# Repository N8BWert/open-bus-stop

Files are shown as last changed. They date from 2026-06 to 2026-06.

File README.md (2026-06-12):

# Informal Bus Display

## Motivation

While traveling abroad, I noticed that a lot of cities (specifically in the Netherlands) have displays at bus stops detailing the next bus arrival.  This is relatively unheard of in the United States (except for at certain Bus Rapid Transit stations) so I figured it would be interesting to create an informal bus display.  This informal bus display is a simple LCD screen attached to a low-powered microcontroller, but we can use the RTC to try to display the next bus arrivals.

## Description

To make the bus riding experience more enjoyable and reliable, a small low-powered microcontroller display can be created to display the static arrival times of buses.  These displays can be created inexpensively and placed throughout the city informally by residents to aid bus riders in knowing when their next bus is scheduled.

To further extend this concept, our team is also looking to create a set of "towers" (raspberry pis) that can relay real-time bus arrival schedules to the low-powered displays via LoRA radios as well as creating a mapping software to display the location of the various bus-stop displays and "towers" to visualize the adoption of the informal bus stop displays.

## Technical Details

A small low-power microcontroller can be attached at each bus stop around the city.  The microcontroller will have the static table of the bus arrival times for the given bus stop.  Additionally, to improve the accuracy of the microcontroller displays a second “tower” can be created from a raspberry pi and a LoRA-capable radio.  The raspberry pi can ping the relevant transit agency’s API to determine the real-time bus arrival times for all bus stations in its local range.  Then it can relay this information via a LoRA radio to the low-power microcontroller displays to give them real-time bus arrival data.  To contribute to the formation of an informal network of the bus displays and towers a web app can be created.  The towers will relay their GPS coordinate as well as the bus stops they are serving to the web application which can create an autonomic map of the serviced area of the informal bus displays.  Additionally, the low-power microcontrollers will still be able to display static bus arrival times when not connected via LoRA, but will need to be manually registered with the central website to be displayed.

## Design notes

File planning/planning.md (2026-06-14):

# Planning

For full production we will need these displays to effectively work without needing to be modified at all.  This means minimizing power consumption and cost, while also enabling the device to recover from full power loss.  With the current prototype, the rp2040's RTC will not recover from a full power loss meaning we'll need a replacement.  Additionally, the lcd1602 display does not have great visibility and the backlight is very costly.  Finally, We will need to use a solar panel to recharge the lipo battery powering the microcontrollers.

## ESP32-C3 Power Stats using Embassy

Active (CPU running without Wifi): ~20-30mA
Light Sleep (Embassy async wait) - ~130uA

Program Loop:
1. Check the RTC time
2. Update the display
3. Light Sleep for 30 seconds

Assuming steps one and two take 500 milliseconds, this gives us the following power draw:
Steps 1 and 2: 30mA * 500 milliseconds
Step 3: 130uA * 30 seconds

So one loop is 30.13mA at 30.5 seconds meaning we are consuming 30.13mA * 30.5s = 918.965mAs = 0.255mAh

Assuming the device was working 24 hours a day, this would be a total of 6.126mAh per day

## 6v 200mA Solar Panel Recharge

Expecting 75% efficiency and full sunlight for 4 hours a day we can recharge about 200mA * 0.75% * 4 hours = 600mA, which we will consider our absolute budget.

## LCD1602 Power Stats

For the prototype I used the LCD1602 to display the upcoming bus arrivals.  With the blue backlight it has a power draw of roughly 45-55mA.

This means over a day of it being on for 24 hours we would consume 1080mAh-1320mAh.

This far exceeds the 600mA budget of our system so we will not be able to use it.

## SSD1309 OLED Display

The display I used in my prototype consumes way too much power to work for the final product.  Another display I'm considering using is a 2.4" SSD1309 display.  This is relatively the same size as the LCD1602 display, but should have a significantly lower power draw.

The SSD1309 seems to draw roughly 20mA for my current application which would mean over 24 hours we would consume 480mAh.

This is solidly within our solar panel recharge rate (6.126 + 480) < 600mA so this is the way to go.

The main downside of the SSD1309 is it is a bit more expensive than the LCD1602, but I think that being able to actually make it through a day is more important than the price in this case.  Additionally, the LCD1602 is hard to see at different angles (and in the sun), whereas the SSD1309 OLED display is visible at all angles and in most levels of sunlight.

## SSD1306 OLED Display

The SSD1309 would be perfect for this project, but its relatively expensive for some reason.  I swear in the past I found them for ~$4-5 a piece, but they're like $12 on the low end now.  For that reason, I'm going to make a prototype with the SSD1306 I2C displays.  They're about 1x1" in display size, but they're also ~$3 a piece.  I'm not 100% certain that they're large enough to be read from near the bus stop though so I need to test that before I commit.

## RTC Selection

The DS3231 seems like the goto Real Time Clock Module for most applications I've seen on the internet so I'll probably choose that for perpetuity

## High-Level Circuit Diagram

```
Solar Cell ---> BQ24074 Solar Cell Lipo Charger ---> LiPo Battery ---> ESP32-C3 ---> SSD1309 Display
                                                                          |
                                                                          |
                                                                          |
                                                                          ---------> RTC (coin cell battery)
                                                                          |
                                                                          |
                                                                          |
                                                                          ---------> Power Switch (power on and off)
```

## Other Considerations

This device needs to be waterproof considering it will be sitting in the elements for years.  In Atlanta, the materials matter a lot considering it can get very hot and humid.  However, I need this to be able to be created by the general population so I think it will need to be able to be 3d printed and/or laser cuttable.  For this reason I will 3d print the majority of the body with white PETG (white to prevent overheating, plus there is UV resistant PETG) and create a front face out of laser cut acrylic.  These are easily accessible hobby manufacturing materials meaning that anyone will be able to make the displays.  To access the PCB for firmware updates and repairs we'll use an O-ring to mate two parts of the 3d printed enclosure.

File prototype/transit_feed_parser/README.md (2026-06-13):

# Transit Feed Parser

## Description

For a large number of transit agencies (at least in the US), google creates a General Transit Feed Specification in partnership with the agency.  To make sure each display has the correct static routes for its location (and to prevent having to upload 20+MB of data to each display device) I created this parser to help extract the necessary transit data for a given bus stop to be included in the display program binary.

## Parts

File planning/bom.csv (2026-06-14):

item | unit cost ($USD) | cumulative cost ($USD) | purchase link
Open Bus Stop PCB | $12.50 | $12.50 | TODO
2000mAh 3.7V LiPo Battery | $6.00 | $18.50 | https://www.amazon.com/JLJLUP-Rechargeable-Integrated-Protection-Development/dp/B0FR9GH966
SSD1306 OLED Display | $3.00 | $21.50 | https://www.amazon.com/Hosyond-Display-Self-Luminous-Compatible-Raspberry/dp/B09T6SJBV5?s=electronics
5V 200mA Solar Panel | $3.20 | $24.70 | https://www.amazon.com/gp/product/B0BML3PR4Z/ref=ewc_pr_img_2?smid=A2MJCDED57HY1D
3D Printed Enclosure | #TODO | #TODO | #TODO

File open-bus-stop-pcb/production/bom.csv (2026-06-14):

Designator | Footprint | Quantity | Value | LCSC Part #
BT1 | BatteryHolder_Keystone_3034_1x20mm | 1 | CR1220
C1, C2, C3, C4, C9 | 1206 | 5 | 10uF
C5, C6, C7 | 1206 | 3 | 1uF
C8 | 0805 | 1 | 0.1uF
D1 | 0603 | 1 | GREEN
D2 | 0603 | 1 | RED
D3, D4 | D_SOD-123 | 2 | D_Schottky
J1 | PinHeader_1x04_P2.54mm_Vertical | 1 | Conn_01x04_Pin
J2 | PinHeader_1x02_P2.54mm_Vertical | 1 | Conn_01x02_Pin
J3 | JST_PH_S2B-PH-K_1x02_P2.00mm_Horizontal | 1 | Conn_01x02
J5 | PinHeader_1x02_P2.54mm_Vertical | 1 | Conn_01x02
P1 | USB_C_Receptacle_GCT_USB4105-xx-A_16P_TopMnt_Horizontal | 1 | USB_C_Plug_USB2.0
R1, R2, R9 | 0603 | 3 | 4.7k
R10 | 0603 | 1 | 5.1k
R11, R12, R3, R4, R5, R6 | 0603 | 6 | 10k
R7 | 0603 | 1 | 1k
R8 | 0603 | 1 | 6.2k
SW2, SW4 | SW_Push_1P1T_XKB_TS-1187A | 2 | SW_Push
U1 | ESP32-C3-MINI-1 | 1 | ESP32-C3-MINI-1
U2 | SOIC-16W_7.5x10.3mm_P1.27mm | 1 | DS3231M
U3 | VQFN-16-1EP_3x3mm_P0.5mm_EP1.6x1.6mm | 1 | BQ24074RGT
U4 | SOT-23-5 | 1 | ME6211C33M5

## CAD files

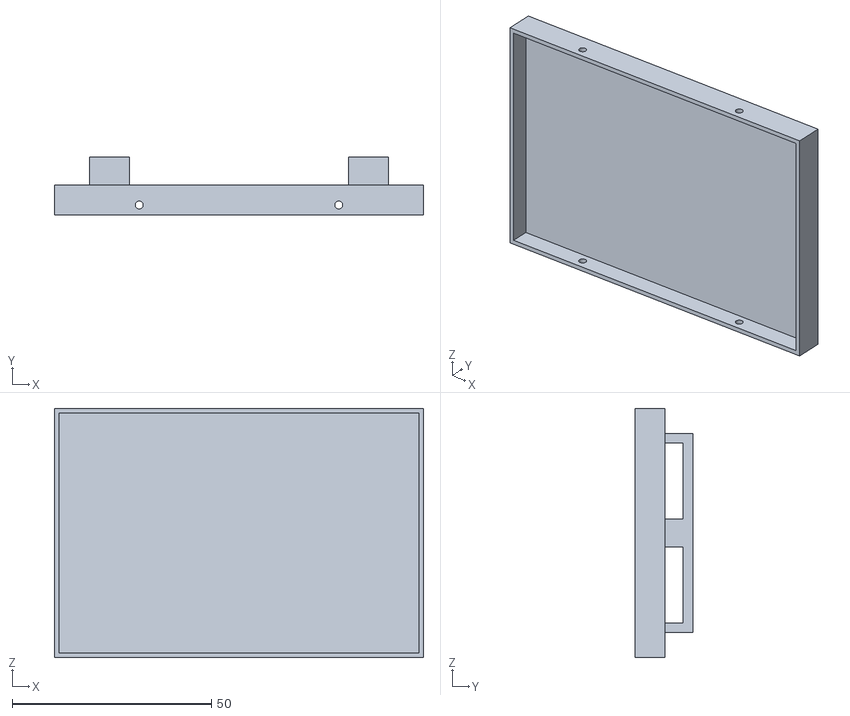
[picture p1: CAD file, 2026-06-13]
CAD/prototype/Back (Meshed).stl
92.5 x 14.5 x 62.5

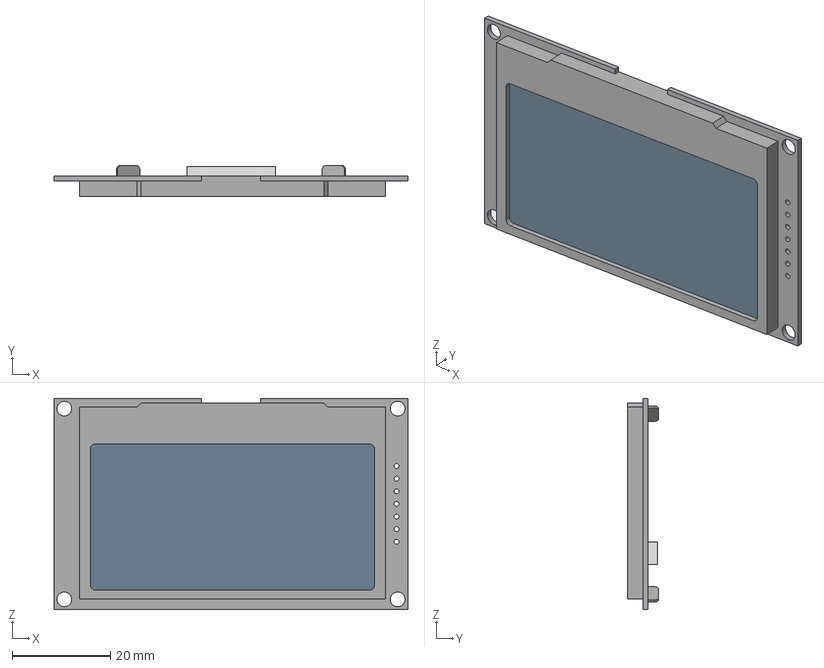
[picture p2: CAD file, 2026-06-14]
CAD/SSD1309 2.42_ OLED v1.step
72.0 x 6.40 x 43.0 mm

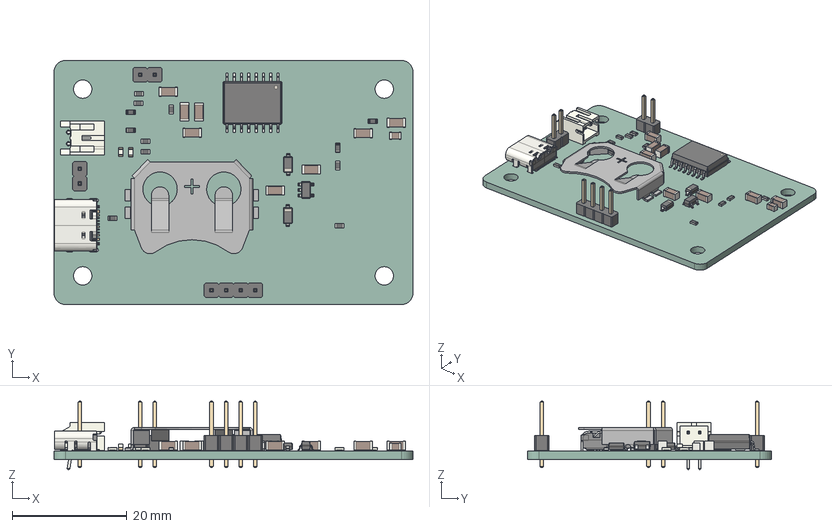
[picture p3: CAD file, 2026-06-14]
open-bus-stop-pcb/.step
62.5 x 42.5 x 11.9 mm
C_1206_3216Metric x 8
R_0603_1608Metric x 12
BatteryHolder_Keystone_3034_1x20mm
SOIC-16W_7.5x10.3mm_P1.27mm
JST_S2B_PH_K
LED_0603_1608Metric x 2
D_SOD-123 x 2
PinHeader_1x02_P254mm_Vertical x 2
PinHeader_1x04_P254mm_Vertical
USB_C_Receptacle_16P_TopMnt_Horizontal_GCT_USB4105-xx-A
SOT-23-5
C_0805_2012Metric
open-bus-stop_PCB

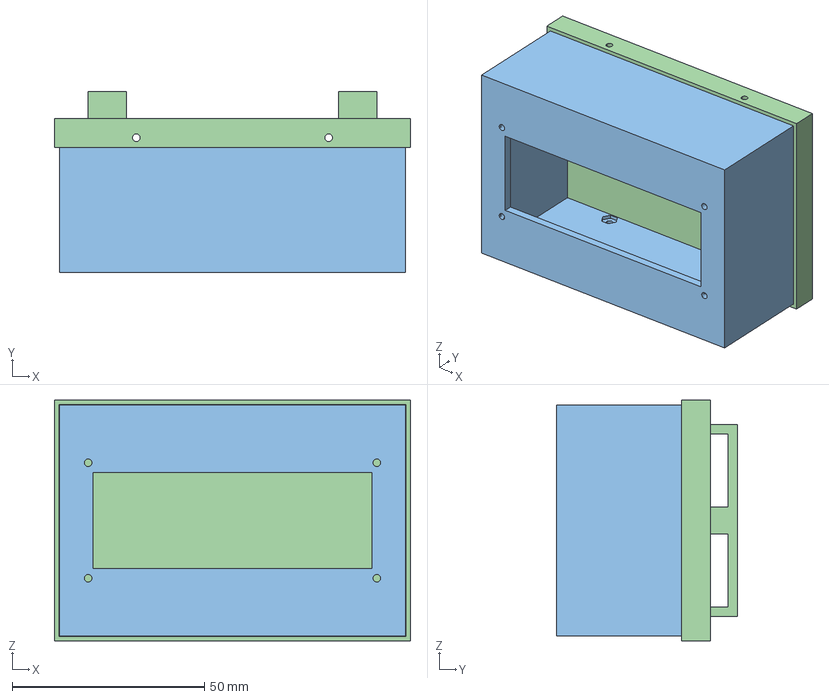
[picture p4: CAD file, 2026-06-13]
CAD/prototype/InformalBusDisplay.FCStd
92.5 x 47.0 x 62.5 mm
Front
Back
Front (Meshed)
Back (Meshed)

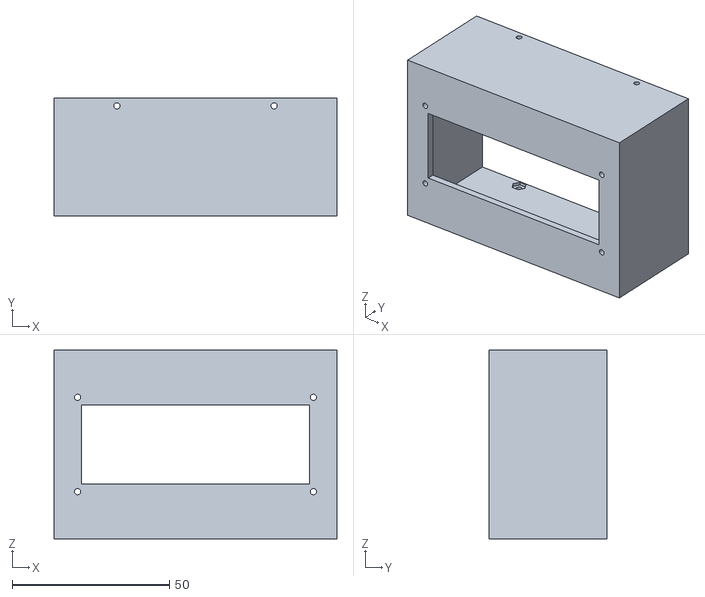
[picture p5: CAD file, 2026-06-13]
CAD/prototype/Front (Meshed).stl
90.0 x 37.5 x 60.0

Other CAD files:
CAD/open-bus-stop.step
CAD/OpenBusStop.FCStd

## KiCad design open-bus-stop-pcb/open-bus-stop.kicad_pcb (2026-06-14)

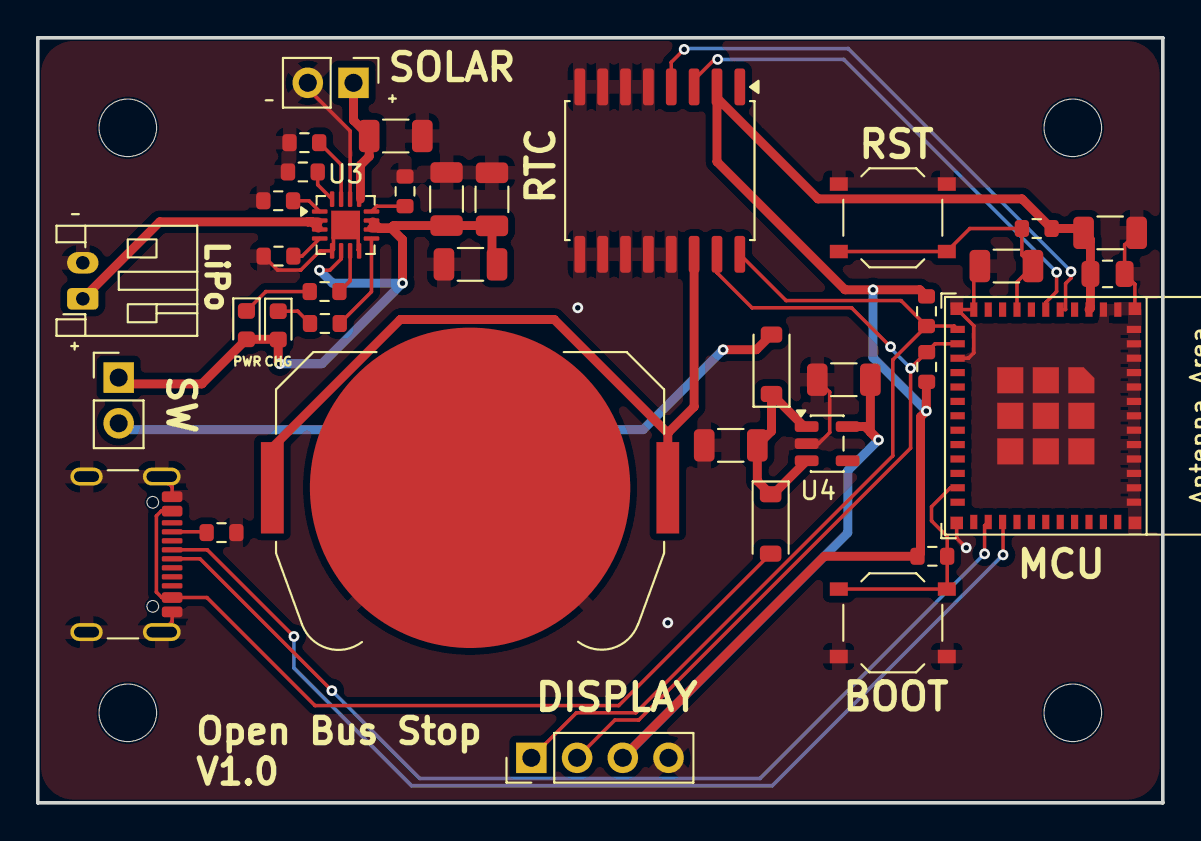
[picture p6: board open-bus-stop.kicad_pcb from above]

Board: 2 copper layers, 62.5 x 42.5 mm, 41 parts (0 on the bottom side), 27 nets.

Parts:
BT1: CR1220; BatteryHolder_Keystone_3034_1x20mm
C1, C2, C3, C4, C9: 10uF; C_1206_3216Metric
C5, C6, C7: 1uF; C_1206_3216Metric
C8: 0.1uF; C_0805_2012Metric
D1: GREEN; LED_0603_1608Metric
D2: RED; LED_0603_1608Metric
D3, D4: D_Schottky; D_SOD-123
H1, H2, H3, H4: MountingHole; MountingHole_3.2mm_M3
J1: Conn_01x04_Pin; PinHeader_1x04_P2.54mm_Vertical
J2: Conn_01x02_Pin; PinHeader_1x02_P2.54mm_Vertical
J3: Conn_01x02; JST_PH_S2B-PH-K_1x02_P2.00mm_Horizontal
J5: Conn_01x02; PinHeader_1x02_P2.54mm_Vertical
P1: USB_C_Plug_USB2.0; USB_C_Receptacle_GCT_USB4105-xx-A_16P_TopMnt_Horizontal
R1, R2, R9: 4.7k; R_0603_1608Metric
R3, R4, R5, R6, R11, R12: 10k; R_0603_1608Metric
R7: 1k; R_0603_1608Metric
R8: 6.2k; R_0603_1608Metric
R10: 5.1k; R_0603_1608Metric
SW2, SW4: SW_Push; SW_Push_1P1T_XKB_TS-1187A
U1: ESP32-C3-MINI-1
U2: DS3231M; SOIC-16W_7.5x10.3mm_P1.27mm
U3: BQ24074RGT; VQFN-16-1EP_3x3mm_P0.5mm_EP1.6x1.6mm
U4: ME6211C33M5; SOT-23-5

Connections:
/D+: P1.A6 (D+), U1.27 (GPIO19/USB_D+)
/D-: P1.A7 (D-), U1.26 (GPIO18/USB_D-)
/RTC_nIRQ: U1.6 (GPIO3/ADC1_CH3), U2.3 (~INT/SQW)
/RTC_nRST: U1.5 (GPIO2/ADC1_CH2), U2.4 (~RST)
/SCL: J1.2, R2.1, U1.13 (GPIO1/ADC1_CH1/XTAL_32K_N), U2.15 (SDA)
/SDA: J1.1, R1.1, U1.12 (GPIO0/ADC1_CH0/XTAL_32K_P), U2.16 (SCL)
/V_BAT: J3.1, U3.2 (BAT), U3.3 (BAT)
/V_IN: C1.2, C2.2, C3.2, D1.2 (A), D2.2 (A), J5.1, U3.6 (EN1), U3.10 (OUT), U3.11 (OUT)
/V_SOL: C4.1, J2.1, U3.13 (IN)
/V_USB: D4.2 (A), P1.A4 (VBUS), P1.A9 (VBUS), P1.B4 (VBUS), P1.B9 (VBUS)
GND: BT1.2 (-), C1.1, C2.1, C3.1, C4.2, C5.2, C6.2, C7.1, C8.1, C9.1, J1.4, J2.2, J3.2, P1.A1 (GND), P1.A12 (GND), P1.B1 (GND), P1.B12 (GND), P1.SH (SHIELD), R5.2, R6.2, R7.2, R8.2, R9.1, R10.1, SW2.1, SW4.2, U1.1 (GND), U1.2 (GND), U1.11 (GND), U1.14 (GND), U1.36 (GND), U1.37 (GND), U1.38 (GND), U1.39 (GND), U1.40 (GND), U1.41 (GND), U1.42 (GND), U1.43 (GND), U1.44 (GND), U1.45 (GND), U1.46 (GND), U1.47 (GND), U1.48 (GND), U1.49 (GND), U1.50 (GND), U1.51 (GND), U1.52 (GND), U1.53 (GND), U2.5 (GND), U2.6 (GND), U2.7 (GND), U2.8 (GND), U2.9 (GND), U2.10 (GND), U2.11 (GND), U2.12 (GND), U2.13 (GND), U3.5 (EN2), U3.8 (VSS), U3.14 (TMR), U3.17 (VSS), U4.2 (V_{SS})
unnamed: BT1.1 (+), U2.14 (VBAT)
unnamed: D1.1 (K), R3.1
unnamed: D2.1 (K), R4.2
unnamed: D3.2 (A), J5.2
unnamed: C5.1, D3.1 (K), D4.1 (K), U4.1 (V_{IN}), U4.3 (CE)
unnamed: P1.A5 (CC), R10.2
unnamed: C7.2, R12.2, SW2.2, U1.8 (EN/CHIP_PU)
unnamed: R11.1, SW4.1, U1.23 (GPIO9)
unnamed: R7.1, U3.12 (ILIM)
unnamed: R8.1, U3.16 (ISET)
unnamed: R9.2, U3.15 (ITERM)
unnamed: R5.1, U3.1 (TS)
unnamed: R6.1, U3.4 (~CE)
unnamed: R4.1, U3.9 (~CHG)
unnamed: R3.2, U3.7 (~PGOOD)
VCC: C6.1, C8.2, C9.2, J1.3, R1.2, R2.2, R11.2, R12.1, U1.3 (3V3), U2.2 (VCC), U4.5 (V_{OUT})

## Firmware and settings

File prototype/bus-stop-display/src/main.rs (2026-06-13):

//!
//! This is the main program for the informal bus stop display.
//!
//! It loads staticly created data for the bus stop and uses it to display the next bus
//! time on an LCD1602 display. It also uses the RTC to keep track of time and schedule alarms
//! to wake up the display when the next bus time is approaching.
//!

#![no_std]
#![no_main]

use embassy_executor::Spawner;
use embassy_rp::bind_interrupts;
use embassy_rp::i2c::{Config, I2c};
use embassy_rp::rtc::{DateTimeFilter, Rtc};
use embassy_time::{Delay, Duration, Timer};
use {defmt_rtt as _, panic_probe as _};

use lcd1602_driver::{
    command::{DataWidth, State},
    lcd::{self, Basic, Ext, Lcd},
    sender::I2cSender,
};

use bus_stop_display::{get_next_stop_time, START};

bind_interrupts!(struct Irqs {
    RTC_IRQ => embassy_rp::rtc::InterruptHandler;
});

fn two_digit_str(n: u8, buf: &mut [u8; 2]) -> &str {
    buf[0] = b'0' + (n / 10);
    buf[1] = b'0' + (n % 10);
    core::str::from_utf8(buf).unwrap()
}

fn three_digit_str(n: u16, buf: &mut [u8; 3]) -> &str {
    buf[0] = b'0' + (n / 100) as u8;
    if buf[0] == b'0' {
        buf[0] = b' ';
    }
    buf[1] = b'0' + (n % 100 / 10) as u8;
    if buf[1] == b'0' && buf[0] == b' ' {
        buf[1] = b' ';
    }
    buf[2] = b'0' + (n % 10) as u8;
    core::str::from_utf8(buf).unwrap()
}

fn four_digit_str(n: u16, buf: &mut [u8; 4]) -> &str {
    buf[0] = b'0' + (n / 1000) as u8;
    buf[1] = b'0' + (n % 1000 / 100) as u8;
    buf[2] = b'0' + (n % 100 / 10) as u8;
    buf[3] = b'0' + (n % 10) as u8;
    core::str::from_utf8(buf).unwrap()
}

#[embassy_executor::main]
async fn main(_spawner: Spawner) {
    let p = embassy_rp::init(Default::default());

    let mut rtc = Rtc::new(p.RTC, Irqs);
    if !rtc.is_running() {
        rtc.set_datetime(START).unwrap();
    }

    let mut i2c_config = Config::default();
    i2c_config.frequency = 50_000;
    i2c_config.sda_pullup = true;
    i2c_config.scl_pullup = true;
    let mut i2c = I2c::new_blocking(p.I2C0, p.PIN_5, p.PIN_4, i2c_config);
    let mut sender = I2cSender::new(&mut i2c, 0x27u8);
    let lcd_config = lcd::Config::default().set_data_width(DataWidth::Bit4);
    let mut delay = Delay;
    let mut lcd = Lcd::new(&mut sender, &mut delay, lcd_config, None);
    lcd.clean_display();
    lcd.return_home();

    lcd.set_backlight(State::On);
    loop {
        let mut now = rtc.now().unwrap();
        let next_stop_time = get_next_stop_time(&now);
        let mut minutes = next_stop_time.minutes_until_stop(now.hour, now.minute, now.second);
        if minutes > 60 {
            lcd.set_backlight(State::Off);
            rtc.schedule_alarm(
                DateTimeFilter::default()
                    .hour((minutes / 60) as u8)
                    .minute((minutes % 60) as u8),
            );
            rtc.wait_for_alarm().await;
            rtc.disable_alarm();
            rtc.clear_interrupt();
            lcd.set_backlight(State::On);
            now = rtc.now().unwrap();
            minutes = next_stop_time.minutes_until_stop(now.hour, now.minute, now.second);
        }

        let mut showing_time = false;
        while !next_stop_time.passed(now.hour, now.minute, now.second) {
            minutes = next_stop_time.minutes_until_stop(now.hour, now.minute, now.second);

            if showing_time {
                for c in two_digit_str(now.month, &mut [0u8; 2]).chars() {
                    lcd.write_char_to_cur(c);
                }
                lcd.write_char_to_cur('/');
                for c in two_digit_str(now.day, &mut [0u8; 2]).chars() {
                    lcd.write_char_to_cur(c);
                }
                lcd.write_char_to_cur('/');
                for c in four_digit_str(now.year, &mut [0u8; 4]).chars() {
                    lcd.write_char_to_cur(c);
                }
                lcd.set_cursor_pos((0, 1));
                for c in two_digit_str(now.hour, &mut [0u8; 2]).chars() {
                    lcd.write_char_to_cur(c);
                }
                lcd.write_char_to_cur(':');
                for c in two_digit_str(now.minute, &mut [0u8; 2]).chars() {
                    lcd.write_char_to_cur(c);
                }
            } else {
                // Display the next bus time
                for c in "Next Bus: ".chars() {
                    lcd.write_char_to_cur(c);
                }
                for c in "  ".chars() {
                    lcd.write_char_to_cur(c);
                }
                for c in three_digit_str(next_stop_time.route.get(), &mut [0u8; 3]).chars() {
                    lcd.write_char_to_cur(c);
                }

                lcd.set_cursor_pos((0, 1));
                if minutes > 1 {
                    for c in two_digit_str(minutes as u8, &mut [0u8; 2]).chars() {
                        lcd.write_char_to_cur(c);
                    }
                    for c in "  min".chars() {
                        lcd.write_char_to_cur(c);
                    }
                } else {
                    for c in "NOW".chars() {
                        lcd.write_char_to_cur(c);
                    }
                }
            }

            Timer::after(Duration::from_secs(10)).await;
            now = rtc.now().unwrap();

            lcd.clean_display();
            lcd.return_home();
            showing_time = !showing_time;
        }
    }
}

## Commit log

2026-06-13 build basic bus display enclosure in FreeCAD
    [Back (Meshed).stl, Front (Meshed).stl, InformalBusDisplay.FCStd]
2026-06-13 remove test prints, flash over usb, display time
2026-06-14 Start working on production version
    [.step, Back (Meshed).stl, Front (Meshed).stl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]
2026-06-14 (WIP) swapping RTCs and Display to decrease BOM cost
    [bom.csv, designators.csv, open-bus-stop.kicad_pcb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]
